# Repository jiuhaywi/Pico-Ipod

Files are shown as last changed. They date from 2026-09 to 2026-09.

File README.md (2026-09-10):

# The Pico 2W Music Player
The Raspberry Pi Pico 2W Music Player is a project based on the apple ipod - a handheld, battery-powered music player.

## Why Did I Create This Project?
> All of the current pocket music players on the market are either **stupidly expensive, bad quality, or low storage** with little to no room for upgrading. Due to this, I wanted to create such a project, creating my own handheld music player instead of using all my phone's battery on music. This project was also something interesting to get into, being my first ever hardware project.



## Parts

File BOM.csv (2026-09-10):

Item Name | Qty | Price (total GBP) | Link
230PCS/lot PH2.0 2p 3p 4p 5p 2.0mm Pitch Terminal Kit Housing Pin Header JST Connector | 1 | 1.83 | https://www.aliexpress.com/item/1005011946689992.html
SanDisk 128GB Ultra microSDXC card + SD adapter | 1 | 22.99 | https://www.amazon.co.uk/SanDisk-128GB-microSDXC-adapter-Performance/dp/B0B7NTY2S6
10PCS SMD Self Elastic TF Card Holder Reader Card Holder Push Type 9pin Double Pressure External Welding TF Card Slot | 1 | 3.54 | https://www.aliexpress.com/item/1005010534403296.html
503450 3.7V 1000mAh Polymer Lithium Rechargeable Battery with JST PH2.0 Plug High Capacity for Camera GPS Navigator MP5 Headset | 2 | 5.44 | https://www.aliexpress.com/item/1005012823920013.html
100pcs 0805 50V SMD Thick Film Chip Multilayer Ceramic Capacitor 10nF | 1 | 1.06 | https://www.aliexpress.com/item/1005006142309480.html
100pcs 0805 50V SMD Thick Film Chip Multilayer Ceramic Capacitor 10uF | 1 | 1.10 | https://www.aliexpress.com/item/1005006142309480.html
100pcs 0805 SMD Resistor Accuracy 1% 1/8W 1K ohm | 1 | 0.89 | https://www.aliexpress.com/item/1005005580397963.html
50pcs/lot 6x6x4.3MM 4PIN G89 Tactile Tact Push Button Micro Switch Direct Plug-in Self-reset DIP Top Copper | 1 | 1.50 | https://www.aliexpress.com/item/32815969627.html
SS12D10 SS12D06 Toggle Switch Straight / Right Angle 3 Pin 1P2T Handle High Slide Toggle Switches | 5 | 1.11 | https://www.aliexpress.com/item/1005006258365679.html
5pcs EC11 30 Position Encoder Switch With Push Button Switch Rotary Encoder Code Switch 5pin Plug-in Type 15mm Half Shaft | 1 | 1.72 | https://www.aliexpress.com/item/1005006685783293.html
20PCS 3.5mm Headphone Jack PJ-327A PJ327A PJ-327 Audio Jack 5 Pin SMD SMT MP3 Accessories PJ-327A High Quality | 1 | 1.32 | https://www.aliexpress.com/item/4000661858732.html
1.3" IPS LCD Display Module (240x240) | 1 | 9.20 | https://thepihut.com/products/1-3-ips-lcd-display-module-240x240
Raspberry Pi Pico2W without headers | 1 | 6.70 | https://thepihut.com/products/raspberry-pi-pico-2-w?variant=54063378727297
Total Cost: | 58.4 GBP | ~80 USD

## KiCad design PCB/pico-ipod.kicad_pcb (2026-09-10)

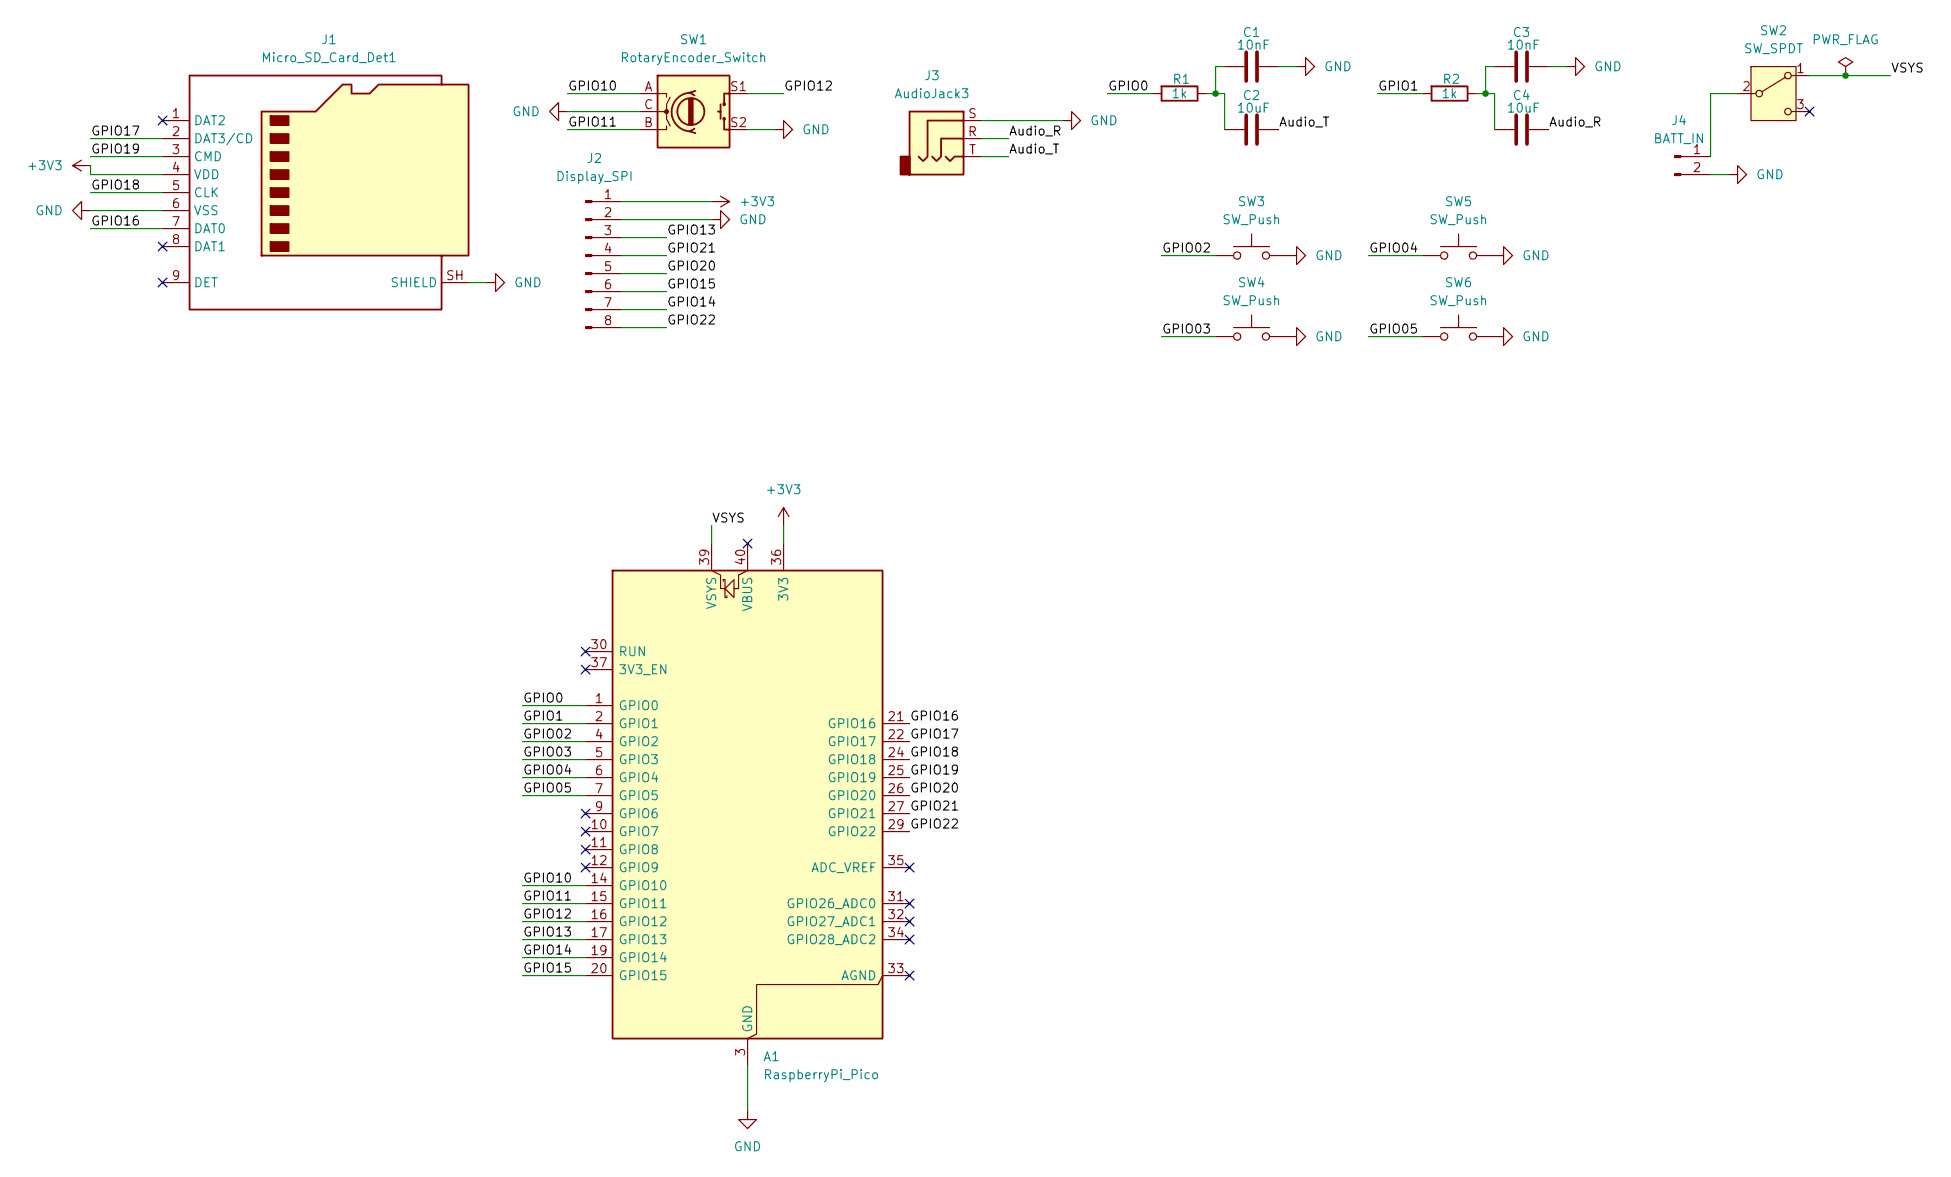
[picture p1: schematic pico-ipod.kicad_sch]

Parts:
A1: RaspberryPi_Pico; RaspberryPi_Pico_Common_Unspecified
C1, C3: 10nF; C_0805_2012Metric
C2, C4: 10uF; C_0805_2012Metric
J1: Micro_SD_Card_Det1; microSD_HC_Hirose_DM3AT-SF-PEJM5
J2: Display_SPI; PinHeader_1x08_P2.54mm_Vertical
J3: AudioJack3; Jack_3.5mm_CUI_SJ-3523-SMT_Horizontal
J4: BATT_IN; JST_PH_S2B-PH-K_1x02_P2.00mm_Horizontal
R1, R2: 1k; R_0805_2012Metric
SW1: RotaryEncoder_Switch; RotaryEncoder_Alps_EC11E-Switch_Vertical_H20mm
SW2: SW_SPDT; SW_Slide_SPDT_Straight_CK_OS102011MS2Q
SW3, SW4, SW5, SW6: SW_Push; SW_SPST_PTS645Sx43SMTR92

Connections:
+3V3: A1.36 (3V3), J1.4 (VDD), J2.1
/Audio_R: C4.2, J3.R
/Audio_T: C2.2, J3.T
/GPIO0: A1.1 (GPIO0), R1.2
/GPIO1: A1.2 (GPIO1), R2.2
/GPIO02: A1.4 (GPIO2), SW3.1
/GPIO03: A1.5 (GPIO3), SW4.1
/GPIO04: A1.6 (GPIO4), SW5.1
/GPIO05: A1.7 (GPIO5), SW6.1
/GPIO10: A1.14 (GPIO10), SW1.A
/GPIO11: A1.15 (GPIO11), SW1.B
/GPIO12: A1.16 (GPIO12), SW1.S1
/GPIO13: A1.17 (GPIO13), J2.3
/GPIO14: A1.19 (GPIO14), J2.7
/GPIO15: A1.20 (GPIO15), J2.6
/GPIO16: A1.21 (GPIO16), J1.7 (DAT0)
/GPIO17: A1.22 (GPIO17), J1.2 (DAT3/CD)
/GPIO18: A1.24 (GPIO18), J1.5 (CLK)
/GPIO19: A1.25 (GPIO19), J1.3 (CMD)
/GPIO20: A1.26 (GPIO20), J2.5
/GPIO21: A1.27 (GPIO21), J2.4
/GPIO22: A1.29 (GPIO22), J2.8
/VSYS: A1.39 (VSYS), SW2.1 (A)
GND: A1.3 (GND), A1.8 (GND), A1.13 (GND), A1.18 (GND), A1.23 (GND), A1.28 (GND), A1.38 (GND), C1.2, C3.2, J1.6 (VSS), J1.SH (SHIELD), J2.2, J3.S, J4.2, SW1.C, SW1.S2, SW3.2, SW4.2, SW5.2, SW6.2
unnamed: C1.1, C2.1, R1.1
unnamed: C3.1, C4.1, R2.1
unnamed: J4.1, SW2.2 (B)

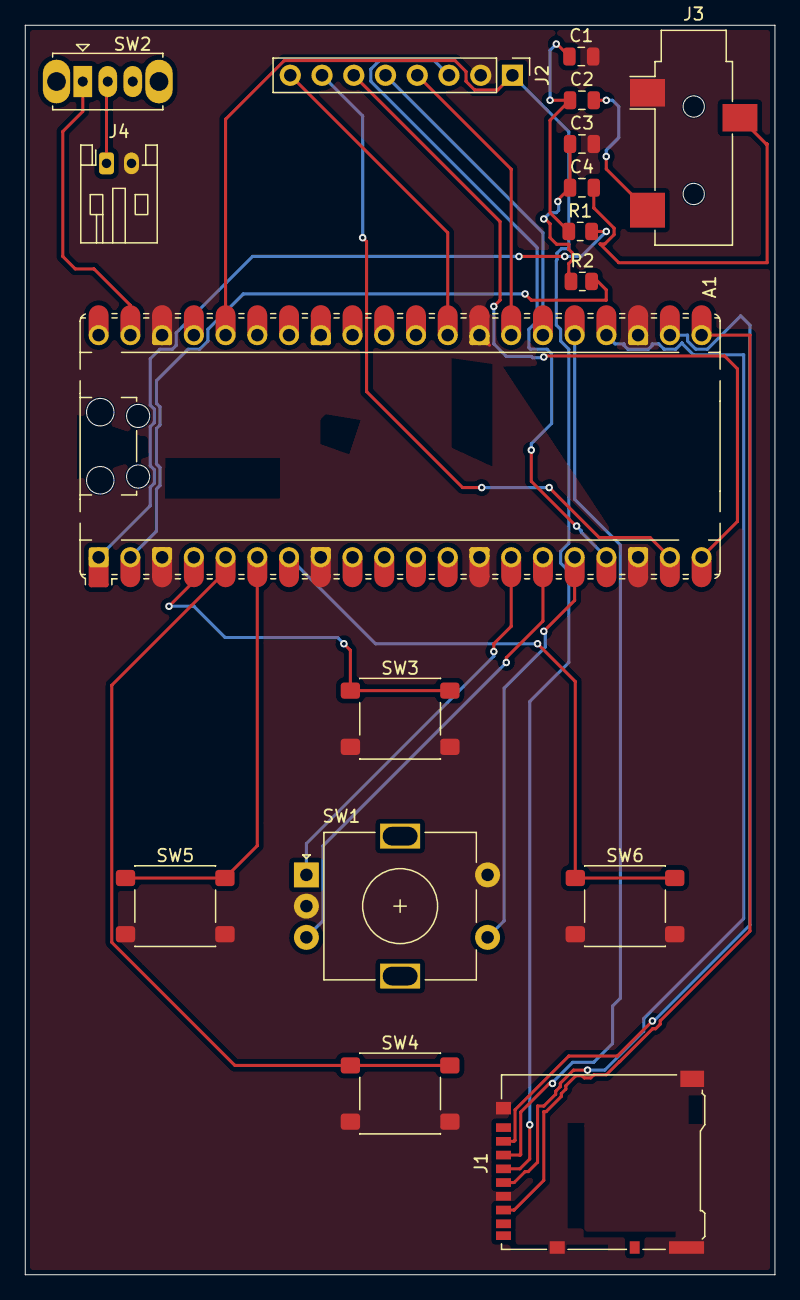
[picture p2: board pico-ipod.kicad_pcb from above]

Board: 2 copper layers, 60.0 x 100.0 mm, 17 parts (0 on the bottom side), 27 nets.

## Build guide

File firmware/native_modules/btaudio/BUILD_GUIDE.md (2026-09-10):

# PicoPod Build Guide

This guide explains how to compile the PicoPod **CircuitPython** firmware, with **btaudio** compiled into the uf2.

## Prerequisites

### Arch Distros:
```bash
sudo pacman -S --needed \
    base-devel \
    arm-none-eabi-gcc \
    arm-none-eabi-binutils \
    arm-none-eabi-newlib \
    cmake \
    ninja \
    python \
    git \
    pkgconf
```

### Debian/Ubuntu Distros:
```bash
sudo apt-get update && sudo apt-get install -y \
    build-essential \
    gcc-arm-none-eabi \
    binutils-arm-none-eabi \
    libnewlib-arm-none-eabi \
    cmake \
    ninja-build \
    python3 \
    git \
    pkg-config
```

---

## Layout

The native module files are found in `firmware/native_modules/btaudio/`:
```
firmware/native_modules/btaudio/
├── shared-bindings/
│   └── btaudio/
│       ├── __init__.c      
│       └── __init__.h      
├── common-hal/
│   └── btaudio/
│       └── __init__.c      
├── build_circuitpython_uf2.sh 
└── BUILD_GUIDE.md          
```

---

## Building

Run the build script:
```bash
chmod +x firmware/native_modules/btaudio/build_circuitpython_uf2.sh
./firmware/native_modules/btaudio/build_circuitpython_uf2.sh
```

Or:
1. **Clone CircuitPython:**
   ```bash
   git clone https://github.com/adafruit/circuitpython.git
   cd circuitpython
   make fetch-submodules
   ```
2. **Copy the `btaudio` module into CircuitPython:**
   ```bash
   cp -r ../native_modules/btaudio/shared-bindings/btaudio shared-bindings/
   cp -r ../native_modules/btaudio/common-hal/btaudio ports/raspberrypi/common-hal/
   ```
3. **Build `mpy-cross`:**
   ```bash
   make -C mpy-cross
   ```
4. **Compile for Pico 2 W:**
   ```bash
   cd ports/raspberrypi
   make BOARD=raspberry_pi_pico2_w -j$(nproc)
   ```

---

## 4. Flashing

1. Hold the **BOOTSEL** button and plug the pico in with USB.
2. Drag and drop `firmware.uf2` onto the `RPI-RP2` drive.
3. Copy all Python files (`code.py`, `display.py`, `input.py`, `audio.py`, `settings.py`, `pinout.py`) and `/songs/` onto the `CIRCUITPY` drive.

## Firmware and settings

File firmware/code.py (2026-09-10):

import time
time.sleep(1)
print("BOOT: code.py started")

import board
import busio
import digitalio
import sdcardio
import storage
import os
import pinout
from input import InputManager
from display import DisplayManager
from audio import AudioPlayer
from settings import SettingsManager

print("BOOT: imports complete")

def mount_sd_card():
    spi = busio.SPI(
        clock=pinout.PIN_SD_CLK,
        MOSI=pinout.PIN_SD_CMD,
        MISO=pinout.PIN_SD_DAT0,
    )
    card = sdcardio.SDCard(spi, pinout.PIN_SD_DAT3)
    storage.mount(storage.VfsFat(card), "/sd")

def scan_songs():
    supported_exts = (".mp3", ".wav")
    found_tracks = []
    search_dirs = ["/sd/songs", "/sd", "/songs"]
    for dir_path in search_dirs:
        try:
            for item in os.listdir(dir_path):
                if item.startswith(".") or item.startswith("._"):
                    continue
                lower = item.lower()
                if any(lower.endswith(ext) for ext in supported_exts):
                    found_tracks.append(item)
            if found_tracks:
                print("Discovered {} tracks in {}".format(len(found_tracks), dir_path))
                break
        except (OSError, RuntimeError):
            pass
            
    if not found_tracks:
        found_tracks = ["Song1.mp3", "Song2.mp3", "Song3.mp3"]
    else:
        found_tracks.sort()
    return found_tracks

def resolve_song_path(filename):
    candidate_paths = [
        "/sd/songs/{}".format(filename),
        "/sd/{}".format(filename),
        "/songs/{}".format(filename),
        "/{}".format(filename),
    ]
    for path in candidate_paths:
        try:
            with open(path, "rb") as f:
                return path
        except (OSError, RuntimeError):
            pass
    return "/sd/songs/{}".format(filename)

inputs = InputManager()
print("BOOT: input ready")
ui = DisplayManager()
print("BOOT: display ready")
player = AudioPlayer()
print("BOOT: audio ready")

try:
    mount_sd_card()
    ui.set_status("SD ready")
    print("SD card mounted successfully")
except (OSError, RuntimeError) as error:
    print("SD card unavailable:", error)
    ui.set_status("No SD card")

settings = SettingsManager()
print("BOOT: settings ready")

tracks = scan_songs()
ui.set_tracks(tracks)
selected_idx = 0
volume = 70
output_modes = ["Audio-Jack", "Bluetooth"]
output_mode_idx = 0

ui.update_selection(selected_idx)
ui.set_volume(volume)
ui.set_output_mode(output_modes[output_mode_idx])
print("Ready: UP/DOWN for songs, RIGHT to play, Encoder turn for Volume, Encoder click for Audio output")

while True:
    track_delta = inputs.get_track_delta()
    if track_delta != 0:
        items = ui.get_items()
        new_idx = max(0, min(len(items) - 1, selected_idx + track_delta))
        if new_idx != selected_idx:
            selected_idx = new_idx
            ui.update_selection(selected_idx)
            print("Selected: " + items[selected_idx])

    vol_delta = inputs.get_volume_delta()
    if vol_delta != 0:
        new_vol = max(0, min(100, volume + vol_delta))
        if new_vol != volume:
            volume = new_vol
            ui.set_volume(volume)
            player.set_volume(volume)
            print("Volume:", volume)

    if inputs.is_output_toggle_pressed():
        output_mode_idx = (output_mode_idx + 1) % len(output_modes)
        mode = output_modes[output_mode_idx]
        ui.set_output_mode(mode)
        player.set_output_mode(mode)
        print("Output mode:", mode)

    if inputs.is_play_pressed():
        items = ui.get_items()
        print("Interact for:", items[selected_idx])
        
        if ui.selected_tab == "music":
            track_name = tracks[selected_idx]
            ui.set_now_playing(track_name)
            try:
                filepath = resolve_song_path(track_name)
                player.play(filepath)
                print("Playing:", filepath)
            except (OSError, RuntimeError) as error:
                print("Unable to play track:", error)
                ui.set_status("Track unavailable")
        elif ui.selected_tab == "settings":
            ui.set_selected_tab("settings/" + items[selected_idx])
            selected_idx = 0
            print("Toggled setting: ", items[selected_idx])
        elif ui.selected_tab == "playlists":
            print("Opened playlist: ", items[selected_idx])
        elif ui.selected_tab == "/":
            ui.set_selected_tab(items[selected_idx])
            selected_idx = 0
            print("Opened tab: ", items[selected_idx])
        elif ui.selected_tab == "settings/theme":
            settings.update_settings("theme", items[selected_idx])
            print("Updated setting 'theme': ", items[selected_idx])
        elif ui.selected_tab == "settings/output":
            choice = items[selected_idx]
            if choice == "Bluetooth":
                ui.set_selected_tab("settings/output/bluetooth")
                selected_idx = 0
                print("Opened Bluetooth device list")
            else:
                settings.update_settings("output", choice)
                ui.set_output_mode(choice)
                player.set_output_mode(choice)
                ui.set_status("Output: " + choice)
                print("Updated setting 'output': ", choice)
        elif ui.selected_tab == "settings/output/bluetooth":
            chosen_device = items[selected_idx]
            if chosen_device == "Scan for devices...":
                ui.set_status("Scanning...")
                print("Scanning for Bluetooth devices...")
                ui.set_status("Scan complete")
            else:
                ui.set_status("Connecting...")
                success = player.connect_bluetooth(chosen_device)
                if success:
                    settings.update_settings("output", "Bluetooth")
                    ui.set_output_mode("Bluetooth")
                    ui.set_status("Connected: " + chosen_device)
                    print("Connected to Bluetooth device:", chosen_device)
                else:
                    ui.set_status("BT Connect Failed")

    if inputs.is_back_pressed():
        print(ui.selected_tab)
        if ui.selected_tab=="/":
            print("Error: back key on root")
        elif ui.selected_tab=="settings":
            settings.save_settings()
            ui.set_selected_tab("/")
            selected_idx = 0
            print("Returned to tab: /")
        elif ui.selected_tab=="music":
            ui.set_selected_tab("/")
            selected_idx = 0
            print("Returned to tab: /")
        elif ui.selected_tab=="playlists":
            ui.set_selected_tab("/")
            selected_idx = 0
            print("Returned to tab: /")
        elif ui.selected_tab=="settings/theme":
            ui.set_selected_tab("settings")
            selected_idx = 0
            print("Returned to tab: settings")
        elif ui.selected_tab=="settings/output/bluetooth":
            ui.set_selected_tab("settings/output")
            selected_idx = 0
            print("Returned to tab: settings/output")
        elif ui.selected_tab=="settings/output":
            ui.set_selected_tab("settings")
            selected_idx = 0
            print("Returned to tab: settings")
        else:
            ui.set_selected_tab("/")
            selected_idx = 0
            print("Back to root tab")
        

    time.sleep(0.005)

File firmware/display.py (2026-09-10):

import displayio
import busio
import terminalio
import digitalio
from adafruit_display_text import label
from adafruit_ili9341 import ILI9341
import pinout

try:
    from fourwire import FourWire
except (ImportError, AttributeError):
    from displayio import FourWire


# Preset Theme: Choose "dark" (Deep Black like Gemini) or "light" (Sleek Light Gray)
THEME = "dark"


def col(rgb_hex):
    """Convert RGB hex to BGR hex to match the ILI9341 panel order."""
    r = (rgb_hex >> 16) & 0xFF
    g = (rgb_hex >> 8) & 0xFF
    b = rgb_hex & 0xFF
    return (b << 16) | (g << 8) | r


THEMES = {
    "dark": {
        "bg": col(0x000000),           # Deep pitch black
        "header_bg": col(0x141416),    # Sleek dark charcoal
        "header_text": col(0xFFFFFF),  # Pure white
        "vol_text": col(0x38BDF8),     # Electric sky cyan
        "bat_text": col(0x4ADE80),     # Battery green
        "section_text": col(0x71717A), # Muted slate
        "selection": col(0x38BDF8),    # Highlight cyan
        "track_unsel": col(0xA1A1AA),  # Clean light gray
        "card_bg": col(0x141416),      # Dark charcoal card
        "card_title": col(0x71717A),   # Section gray
        "track_name": col(0xFFFFFF),   # Crisp white
        "track_state": col(0x4ADE80),  # Bright green
        "output_mode": col(0x38BDF8),  # Cyan
        "status_bg": col(0x000000),    # Deep pitch black
        "status_text": col(0xA1A1AA)   # Gray
    },
    "light": {
        "bg": col(0xF3F4F6),           # Soft light gray
        "header_bg": col(0xE5E7EB),    # Medium light gray
        "header_text": col(0x111827),  # Dark slate
        "vol_text": col(0x0284C7),     # Blue
        "bat_text": col(0x16A34A),     # Green
        "section_text": col(0x4B5563), # Slate
        "selection": col(0x0284C7),    # Blue highlight
        "track_unsel": col(0x374151),  # Dark slate
        "card_bg": col(0xFFFFFF),      # Clean white card
        "card_title": col(0x4B5563),   # Slate
        "track_name": col(0x111827),   # Black
        "track_state": col(0x16A34A),  # Green
        "output_mode": col(0x0284C7),  # Blue
        "status_bg": col(0xE5E7EB),    # Gray
        "status_text": col(0x374151)   # Dark slate
    }
}


def create_rect(width, height, color, x=0, y=0):
    bitmap = displayio.Bitmap(width, height, 1)
    palette = displayio.Palette(1)
    palette[0] = color
    return displayio.TileGrid(bitmap, pixel_shader=palette, x=x, y=y)


class DisplayManager:
    def __init__(self):
        self.init_vars()
        self.initialize_display()



    def init_vars(self):
        self.colors = THEMES.get(THEME, THEMES["dark"])
        self.display = None
        self.backlight = None
        self.group = displayio.Group()
        self.tracks = ["Song1.mp3", "Song2.mp3", "Song3.mp3"]
        self.selected_idx = 0
        self.scroll_offset = 0
        self.visible_count = 3
        self.volume = 70
        self.output_mode = "Audio-Jack"
        self.tab_labels = []
        self.vol_label = None
        self.bat_label = None
        self.now_playing_track = None
        self.now_playing_state = None
        self.now_playing_mode = None
        self.status_label = None
        self.selected_tab = "/"
        self.card_title = None
        self.menu_title = None
        self.root_tabs = ["settings", "music", "playlists"]
        self.settings = ["theme","output"]
        self.settings_theme = ["dark","light"]
        self.settings_output = ["Audio-Jack", "Bluetooth"]
        self.bt_devices = ["AirPods Pro", "Sony WH-1000XM4", "JBL Flip", "Scan for devices..."]
        self.playlists = ["playlist1"]



    def initialize_display(self):
        self.group = displayio.Group()
        self.tab_labels = []
        displayio.release_displays()
        spi = busio.SPI(clock=pinout.PIN_DISPLAY_CLK, MOSI=pinout.PIN_DISPLAY_DIN)
        display_bus = FourWire(
            spi,
            command=pinout.PIN_DISPLAY_DC,
            chip_select=pinout.PIN_DISPLAY_CS,
            reset=pinout.PIN_DISPLAY_RST,
            baudrate=40_000_000
        )
        
        # 240x240 native square resolution
        self.display = ILI9341(
            display_bus,
            width=240,
            height=240,
            rotation=0
        )

        self.backlight = digitalio.DigitalInOut(pinout.PIN_DISPLAY_BL)
        self.backlight.direction = digitalio.Direction.OUTPUT
        self.backlight.value = True

        # 1. Main Background
        bg = create_rect(240, 240, self.colors["bg"], 0, 0)
        self.group.append(bg)

        # 2. Header Bar (Height 32)
        header_bg = create_rect(240, 32, self.colors["header_bg"], 0, 0)
        self.group.append(header_bg)

        header_title = label.Label(
            terminalio.FONT,
            text="PicoPod",
            color=self.colors["header_text"],
            x=8,
            y=16,
            scale=2
        )
        self.group.append(header_title)

        # Volume level (to the left of the battery)
        self.vol_label = label.Label(
            terminalio.FONT,
            text="V: 70%",
            color=self.colors["vol_text"],
            x=116,
            y=16,
            scale=1
        )
        self.group.append(self.vol_label)

        # High-contrast Battery indicator
        self.bat_label = label.Label(
            terminalio.FONT,
            text="[###]",
            color=self.colors["bat_text"],
            x=185,
            y=16,
            scale=1
        )
        self.group.append(self.bat_label)

        # 3. Section Title
        self.menu_title = label.Label(
            terminalio.FONT,
            text=self.selected_tab,
            color=self.colors["section_text"],
            x=10,
            y=44,
            scale=1
        )
        self.group.append(self.menu_title)

        # 4. Track List Labels (3 tracks, 28px spacing)
        self.draw_tab()

        # 5. Now Playing Card (Y: 144 to 206)
        card_bg = create_rect(222, 62, self.colors["card_bg"], 9, 144)
        self.group.append(card_bg)

        self.card_title = label.Label(
            terminalio.FONT,
            text="NOW PLAYING",
            color=self.colors["card_title"],
            x=16,
            y=155,
            scale=1
        )
        self.group.append(self.card_title)

        self.now_playing_track = label.Label(
            terminalio.FONT,
            text="None",
            color=self.colors["track_name"],
            x=16,
            y=175,
            scale=2
        )
        self.group.append(self.now_playing_track)

        self.now_playing_state = label.Label(
            terminalio.FONT,
            text="Idle",
            color=self.colors["track_state"],
            x=16,
            y=195,
            scale=1
        )
        self.group.append(self.now_playing_state)
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

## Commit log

2026-08-26 Added compiled Gerbers
2026-08-26 Added BOM
    [BOM.csv]
2026-08-27 updated BOM
    [BOM.csv]
2026-09-10 Added schem and pcb files
    [pico-ipod.kicad_pcb, pico-ipod.kicad_sch]
2026-09-10 Updated sch
    [pico-ipod.kicad_sch]
2026-09-10 Strip bodystyle
    [pico-ipod.kicad_sch]
2026-09-10 Updated PCB
    [BOM.csv]
